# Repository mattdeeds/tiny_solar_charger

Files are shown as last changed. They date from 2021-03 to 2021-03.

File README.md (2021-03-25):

# Tiny Solar Charger
Less than one inch square solar charging board based on the bq25504 solar harvesting ic with onboard solar cell for low power applications

## Parts 
- KXOB25-04X3F-TR: MONOCRYSTL SOLAR CELL 22MW 2.07V 
- TI BQ25504: Ultra Low-Power Boost Converter With Battery Management 
### Configuration
Currently configured for single cell li-ion batteries but I've tested it with supercapacitors with voltage ratings over 4.2v

BAT_OV = 4.2v
BAT_UV = 3.0v 

Configuration resistor values: 
- R6 = 4.02M
- R7 = 16M 
- R8 = 4.42M
- R9 = 5.49M
- R10 = 4.22M
- R11 = 5.9M
- R12 = 5.620M
- R13 = 3.830M 
- R14 = 0.619M

### Board Pinout and Overview


### Todo/improvements
- Schematic specifies an inductor that I'm not actually using, switched to a higher max current 
- Currently using inductor with 300ma max current, datasheet specifies >300ma

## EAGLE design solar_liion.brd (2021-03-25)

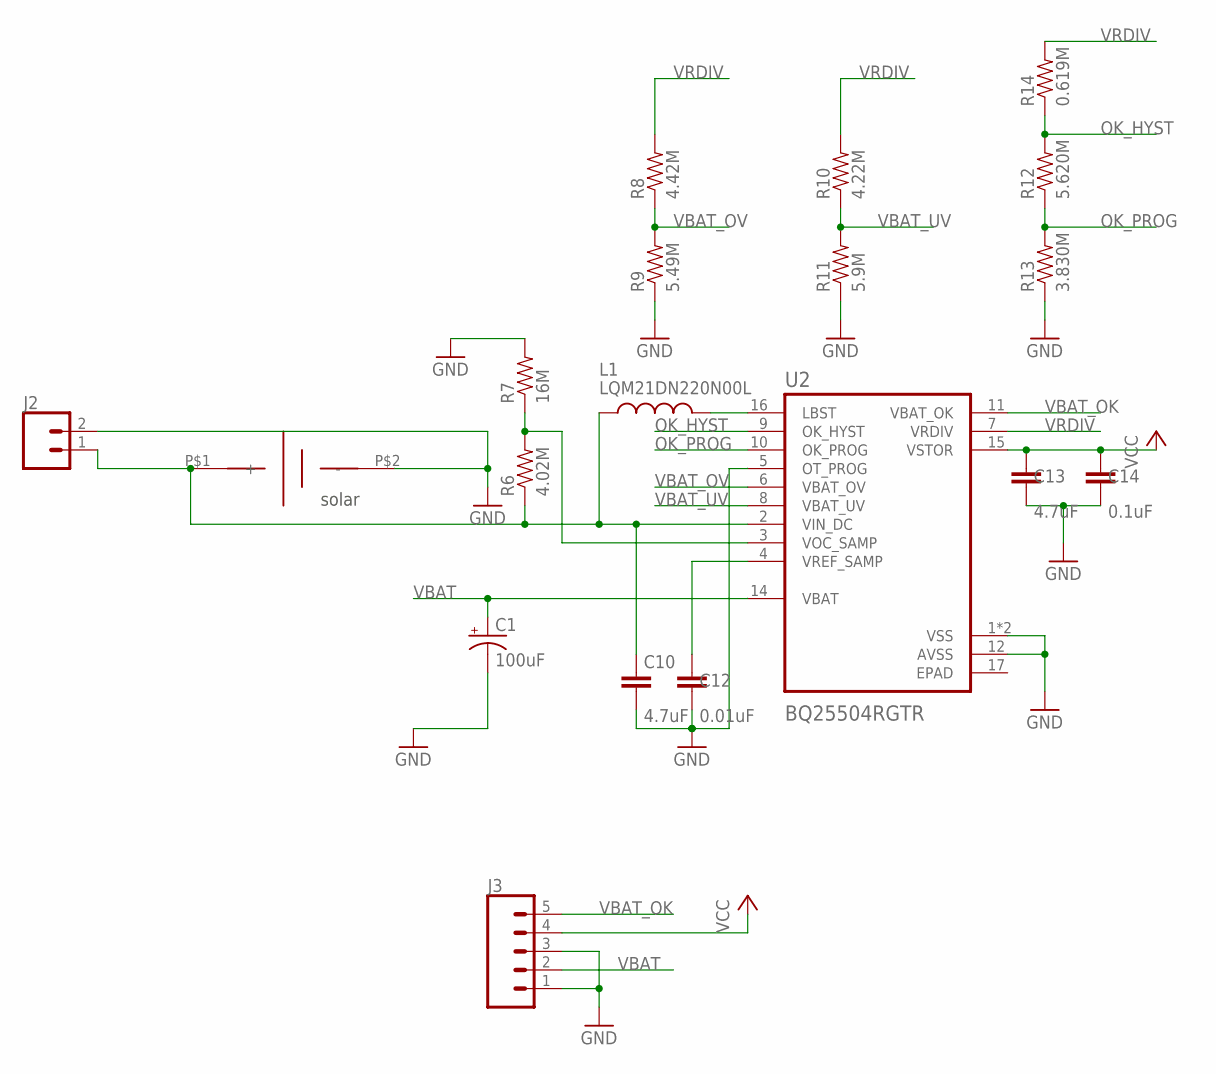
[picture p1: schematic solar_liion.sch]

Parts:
C1: 100uF; EIA7343
C10, C13: 4.7uF; 0603
C12: 0.01uF; 0603
C14: 0.1uF; 0603
J2: CONN_02; 1X02
J3: CONN_05; 1X05
L1: LQM21DN220N00L; INDC2012X145N
R6: 4.02M; 0603
R7: 16M; 0603
R8: 4.42M; 0603
R9: 5.49M; 0603
R10: 4.22M; 0603
R11: 5.9M; 0603
R12: 5.620M; 0603
R13: 3.830M; 0603
R14: 0.619M; 0603
U2: BQ25504RGTR; QFN50P300X300X100-17N
U$3: KXOB25-04X3F-TR

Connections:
EPAD: U2.17 (EPAD)
GND: C1.C (-), C10.2, C12.2, C13.2, C14.2, J2.2, J3.1, J3.3, R7.2, R9.1, R11.1, R13.1, U2.1 (VSS), U2.5 (OT_PROG), U2.12 (AVSS), U2.13 (VSS), U$3.P$2 (-)
unnamed: C10.1, J2.1, L1.1, R6.1, U2.2 (VIN_DC), U$3.P$1 (+)
unnamed: L1.2, U2.16 (LBST)
unnamed: C12.1, U2.4 (VREF_SAMP)
unnamed: R6.2, R7.1, U2.3 (VOC_SAMP)
OK_HYST: R12.2, R14.1, U2.9 (OK_HYST)
OK_PROG: R12.1, R13.2, U2.10 (OK_PROG)
VBAT: C1.A (+), J3.2, U2.14 (VBAT)
VBAT_OK: J3.5, U2.11 (VBAT_OK)
VBAT_OV: R8.1, R9.2, U2.6 (VBAT_OV)
VBAT_UV: R10.1, R11.2, U2.8 (VBAT_UV)
VCC: C13.1, C14.1, J3.4, U2.15 (VSTOR)
VRDIV: R8.2, R10.2, R14.2, U2.7 (VRDIV)

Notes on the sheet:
solar

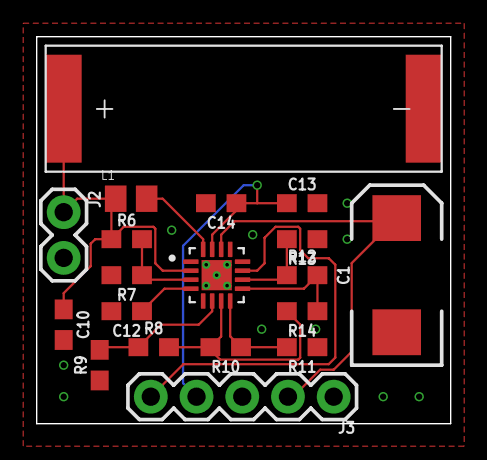
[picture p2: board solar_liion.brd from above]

Board: 2 copper layers, 23.0 x 21.5 mm, 19 parts (0 on the bottom side), 13 nets.

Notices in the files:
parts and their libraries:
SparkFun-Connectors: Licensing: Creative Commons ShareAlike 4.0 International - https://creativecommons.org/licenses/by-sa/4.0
